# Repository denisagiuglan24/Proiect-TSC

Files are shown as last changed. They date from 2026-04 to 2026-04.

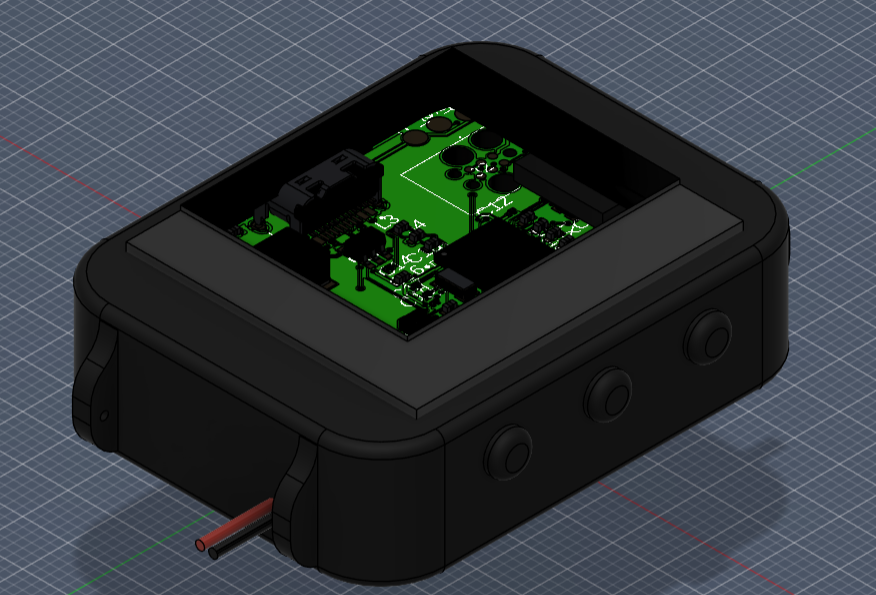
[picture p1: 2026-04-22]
Images/Screenshot 2026-04-22 121332.png

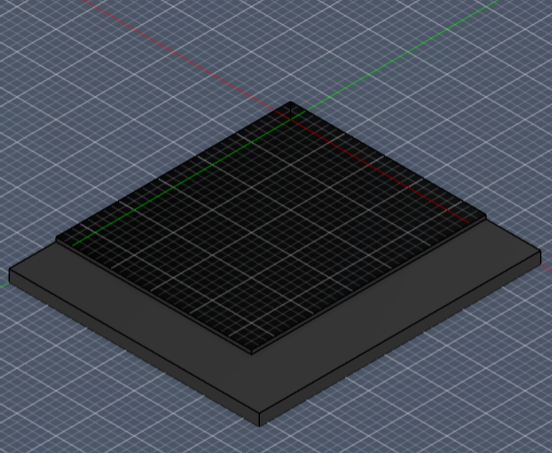
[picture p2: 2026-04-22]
Images/Screenshot 2026-04-22 121447.png

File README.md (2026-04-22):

# Proiect TSC - InkTime Smartwatch
**Student:** Giuglan Denisa-Cristina  
**Grupa:** 334CD  
---

## 1. Viziunea Proiectului si Arhitectura Sistemului

### Diagrama Bloc Hardware
Am structurat conexiunile pentru a separa magistrala rapida SPI (display) de magistrala senzorilor I2C, asigurand astfel o integritate maxima a semnalului.

```text
       ALIMENTARE (POWER)             SISTEM CENTRAL (MCU)                INTERFETE I/O
    _____________________          ___________________________          ____________________
   |                     |        |                           |        |                    |
   |   USB-C Connector   |---5V---|      nRF52840 (SoC)       |--SPI-->|   DISPLAY E-PAPER  |
   |_____________________|        |    Cortex-M4F @ 64MHz     |   Bus  |   (1.54" 24-pin)   |
              |                   |___________________________|        |____________________|
              v                    | P0.02 (SCK) | P0.03 (MOSI)
    _____________________          | P0.15 (DC)  | P0.16 (RST)          ____________________
   |                     |        |___________________________|        |                    |
   |   BQ25180 Charger   |--VBAT--|      MAGISTRALA I2C       |<------>|   ACCEL. BMA421    |
   |  (Li-Po Management) |        |      (SDA / SCL)          |   Bus  |   MAX17048 GAUGE   |
   |_____________________|        |___________________________|        |   DRV2605 HAPTIC   |
              ^                    | P0.26 (SDA) | P0.27 (SCL)         |____________________|
              |                    |___________________________|
    __________|__________          |                           |        ____________________
   |                     |         |   GPIO / PWM CONTROL      |       |                    |
   |   BATERIE LI-PO     |         |                           |------>|   MOTOR VIBRATII   |
   |      250 mAh        |         | P1.11 (PWM) | P0.13 (UP)  |       |____________________|
   |_____________________|         | P0.14 (ENT) | P1.02 (DN)  |<------|    3x BUTOANE      |
              |                    |___________________________|       |____________________|
              v                              |
    _____________________          __________|__________                ____________________
   |                     |        |                     |              |                    |
   |   RT6160A BUCK-B    |--3.3V--|   CRISTAL EXTERN    |------------->|      ANTENA RF     |
   |  (System Power)     |        |    (32.768 kHz)     |              |     (2.4 GHz)      |
   |_____________________|        |_____________________|              |____________________|
```
## 2. Documentatia Componentelor (BOM)

Am selectat componentele bazandu-ma pe catalogul **JLC Parts**, urmarind un raport optim intre dimensiune si performanta. Toate piesele pasive (rezistente/condensatoare) sunt in capsule **0201** si **0402**.

| Componenta | Package | Cod JLC Parts | Datasheet |
|:---|:---|:---|:---|
| **nRF52840-QIAA-R** (MCU) | aQFN73 | [C190794](https://jlcpcb.com/partdetail/Nordic_Semicon-NRF52840_QIAA_R/C190794) | [Link](https://docs.nordicsemi.com/) |
| **E-Paper Display 1.54"** | 24-pin FPC | [C359944](https://jlcpcb.com/partdetail/Waveshare-4_2inch_e_PaperModule/C359944) | [Link](https://www.waveshare.com/w/upload/e/e6/1.54inch_e-Paper_Datasheet.pdf) |
| **BQ25180YBGR** (Charger) | DSBGA-9 | [C3682423](https://jlcpcb.com/partdetail/TexasInstruments-BQ25180YBGR/C3682423) | [Link](https://www.ti.com/lit/ds/symlink/bq25180.pdf) |
| **RT6160AWSC** (Buck-Boost) | WLCSP-15 | [C7065276](https://jlcpcb.com/partdetail/Richtek_Tech-RT6160AWSC/C7065276) | [Link](https://www.richtek.com/assets/product_file/RT6160A/DS6160A-05.pdf) |
| **BMA421** (Accel) | LGA-12 | [C5242966](https://jlcpcb.com/partdetail/Bosch_Sensortec-BMA421/C5242966) | [Link](https://www.bosch-sensortec.com/media/boschsensortec/downloads/datasheets/bst-bma421-ds004.pdf) |
| **MAX17048G+T10** (Gauge) | DFN-8 | [C2682616](https://jlcpcb.com/partdetail/AnalogDevices-MAX17048G_T10/C2682616) | [Link](https://www.analog.com/media/en/technical-documentation/data-sheets/MAX17048-MAX17049.pdf) |
| **DRV2605YZFR** (Haptic) | VSSOP-10 | [C81079](https://jlcpcb.com/partdetail/TexasInstruments-DRV2605YZFR/C81079) | [Link](https://www.ti.com/lit/ds/symlink/drv2605.pdf) |
| **Antenna (2450AT18B100E)** | SMD 3216 | [C5179427](https://jlcpcb.com/partdetail/Johanson_Technology-2450AT18B100E/C5179427) | [Link](https://www.johansontechnology.com/datasheets/2450AT18B100/2450AT18B100.pdf) |
| **KH-TYPE-C-16P** (USB) | 16-pin SMD | [C2765186](https://jlcpcb.com/partdetail/Kinghelm-KH_TYPE_C_16P/C2765186) | [Link](https://datasheet.lcsc.com/lcsc/2012121836_Kinghelm-KH-TYPE-C-16P_C2765186.pdf) |
| **Molex 503480-2400** (FPC) | 24-pin SMD | [C2857168](https://jlcpcb.com/partdetail/Molex-5034802400/C2857160) | [Link](https://www.molex.com/en-us/products/part-detail/5034802400) |
| **USBLC6-2SC6Y** (ESD) | SOT-23-6 | [C7519](https://jlcpcb.com/partdetail/Stmicroelectronics-USBLC6_2SC6Y/C7519) | [Link](https://www.st.com/resource/en/datasheet/usblc6-2.pdf) |
| **Si2301CDS** (P-FET) | SOT-23 | [C10487](https://jlcpcb.com/partdetail/Vishay-Si2301CDS-T1-GE3/C10487) | [Link](https://www.vishay.com/docs/68749/si2301cds.pdf) |
| **EVP-AKB31A** (Butoane) | SMD Tactile | [C2845028](https://jlcpcb.com/partdetail/Panasonic-EVP_AKE31A/C2845028) | [Link](https://industrial.panasonic.com/cdbs/www-data/pdf/ATV0000/ATV0000CE3.pdf) |
| **Motor Vibratii** | Wire leads | [C7528006](https://jlcpcb.com/partdetail/7528806-LCM1027B3605F/C7528806) | [Link](https://datasheet.lcsc.com/lcsc/2310131633_LCM-LCM1027B3605F_C7528806.pdf) |
| **Crystal 32 MHz** | 2016 | [C5265841](https://jlcpcb.com/partdetail/Huiyuancrystal-HY32MSMD2016CA1R30/C5265841) | [Link](https://www.lcsc.com/product-detail/C7275071.html) |
| **Crystal 32.768 kHz** | 3215 | [C70509](https://jlcpcb.com/partdetail/NDK-NX3215SA_32_768KHZ_EXS00AMU00466/C70509) | [Link](https://www.ndk.com/images/products/catalog/c_NX3215SA_e.pdf) |
| **Inductor 0.47uH** | 2016 | [C5832368](https://jlcpcb.com/partdetail/6763488-FTC252012SR47MBCA/C5832368) | [Link](https://www.lcsc.com/product-detail/C5832368.html) |
| **Inductor 10uH** | 0402 | [C910650](https://jlcpcb.com/partdetail/MurataElectronics-LQW15DN100M00D/C910650) | [Link](https://www.murata.com/en-us/products/productdetail?partno=LQW15DN100M00%23) |
| **Rezistenta 10k Ω** | 0201 | [C100126](https://jlcpcb.com/partdetail/LIZElec-CR0201FH1002G/C100126) | [Link](https://www.lcsc.com/product-detail/C100126.html) |
| **Rezistenta 5.1k Ω** | 0201 | [C100142](https://jlcpcb.com/partdetail/LIZElec-CR0201FH5101G/C100142) | [Link](https://www.lcsc.com/product-detail/C5266011.html) |
| **Condensator 1uF** | 0402 | [C14445](https://jlcpcb.com/partdetail/15107-CL05A105KP5NNNC/C14445) | [Link](https://weblib.samsungsem.com/) |
| **Condensator 100nF** | 0201 | [C49062](https://jlcpcb.com/partdetail/50070-CL03A104KP3NNNC/C49062) | [Link](https://www.lcsc.com/product-detail/C49062.html) |
| **Condensator 4.7uF** | 0402 | [C23687](https://jlcpcb.com/partdetail/TDK-C1005X5R0J475MTJ00E/C23687) | [Link](https://www.lcsc.com/product-detail/C23687.html) |
| **Condensator 22uF** | 0402 | [C105226](https://jlcpcb.com/partdetail/106441-CL05A226MQ5QUNC/C105226) | [Link](https://www.lcsc.com/product-detail/C105226.html) |
| **Condensator 12pF** | 0201 | [C50391](https://jlcpcb.com/partdetail/51400-0201CG120J500NT/C50391) | [Link](https://www.lcsc.com/product-detail/C50391.html) |
| **LiPo 250mAh** | Baterie | - | [Link](https://www.tme.eu/Document/b9e12bf26ad0ba929a22ab5d58f022cd/AKY0106.pdf) |
| **TC2030-IDC** (Debug) | Footprint | - | [Link](https://www.tag-connect.com/product/tc2030-idc) |

---

## 3. Analiza Functionalitatii Hardware

In aceasta faza a proiectului, m-am concentrat pe implementarea unui sistem care sa poata functiona independent de o sursa de curent externa pentru perioade lungi.

### 3.1 Unitatea Centrala si Conectivitatea
Am optat pentru **nRF52840** datorita arhitecturii sale flexibile. Acesta imi permite sa folosesc USB-ul nativ pentru debug si transfer de date, in timp ce interfata radio BLE asigura sincronizarea cu telefonul. Pentru a asigura o precizie ridicata a timpului, am adaugat un cristal extern de **32.768 kHz**, esential pentru ca ceasul sa nu piarda secunde in modurile sleep.

### 3.2 Sistemul de Afisaj E-Paper
In loc de un ecran clasic care necesita iluminare constanta, am integrat un display E-Paper de 1.54 inch. Acesta utilizeaza particule incarcate electric care isi pastreaza pozitia fara consum de energie. Am conectat ecranul prin **SPI**, trimitand datele la frecventa maxima suportata pentru a finaliza refresh-ul rapid si a permite procesorului sa intre inapoi in starea de consum minim.

### 3.3 Managementul Energiei
Alimentarea este asigurata de o baterie Li-Po de 250mAh. Am integrat un circuit **Buck-Boost RT6160A** pentru a ma asigura ca, indiferent de nivelul de descarcare al bateriei (intre 4.2V si 3.0V), sistemul primeste un 3.3V stabil. Incarcarea este gestionata inteligent de **BQ25180**, iar monitorizarea procentului bateriei se face prin **MAX17048**, care raporteaza datele catre MCU prin magistrala I2C.

---

## 4. Alocarea Pinilor nRF52840 (Justificare Tehnica)

In procesul de layout, am ales pinii pentru a optimiza rutarea si a separa semnalele de mare viteza de cele de control.

| Pin nRF | Conectat la | Ratiune Tehnica / Explicatie |
|:---|:---|:---|
| **P0.02** | E-Paper SCK | Pin de clock SPI de mare viteza, ales pentru capabilitatea High-Drive. |
| **P0.03** | E-Paper MOSI | Linie de date SPI catre display, plasata langa clock pentru a asigura integritatea semnalului. |
| **P0.15** | E-Paper DC | Data/Command select, esential pentru protocolul controller-ului EPD. |
| **P0.26** | I2C SDA | Linie de date pentru magistrala comuna (IMU, Fuel Gauge, Haptic). |
| **P0.27** | I2C SCL | Semnal de ceas pentru magistrala I2C. |
| **P1.11** | PWM Haptic | Controlul motorului de vibratii, plasat pe Portul 1 pentru a izola zgomotul de comutatie. |
| **P0.13** | Button UP | Intrare GPIO cu rezistenta pull-up interna; poate trezi MCU din sleep (SENSE). |
| **P0.14** | Button ENTER| Intrare digitala pentru selectie si confirmare in meniu. |
| **P1.02** | Button DOWN | Navigare interfata utilizator. |
| **SWDIO / SWDCLK**| Debug/Prog | Interfata Serial Wire Debug folosita pentru programare prin header-ul Tag-Connect. |

---

## 5. Estimarea Consumului si Autonomia

Am proiectat InkTime cu un consum in "Deep Sleep" (System ON) estimat la **~84 uA** (MCU sleep, RTC activ, senzori in low-power).
* In timpul unui **refresh de ecran**, avem un varf de consum de pana la **15 mA** pentru o durata scurta.
* In modul **standby**, tehnologia E-Ink consuma **0 mA** pentru a mentine imaginea.

**Calcul Autonomie:** Cu o baterie de 250 mAh, la un regim de utilizare mediu (refresh ceas o data pe minut si notificari BLE), autonomia estimata este de **~30 de zile**, oferind o experienta superioara smartwatch-urilor clasice.

---

## 6. Design Mecanic si Integrare 3D

Integrarea componentelor a fost realizata in **Fusion 360**, adoptand o structura compacta de tip sandwich:
* **Carcasa Superioara:** Protejeaza display-ul si asigura etanseitatea.
* **PCB:** Placa de 2 straturi pe care sunt montate toate componentele SMD.
* **Carcasa Inferioara:** Gazduieste bateria Li-Po si motorul haptic, fiind fixata prin presare si suruburi de precizie.
Am generat fisierele **.step** pentru vederea explodata si **.f3z** pentru proiectul sursa, asigurand compatibilitatea cu procesele de fabricatie.

---

## 📂 Organizare Repository
* **/Hardware**: Schema electronica (.sch) si design PCB (.brd).
* **/Manufacturing**: Arhiva Gerber, fisiere BOM si Pick&Place.
* **/Mechanical**: Modele CAD 3D (.step, .f3z).
* **/Images**: Randari si capturi de ecran.

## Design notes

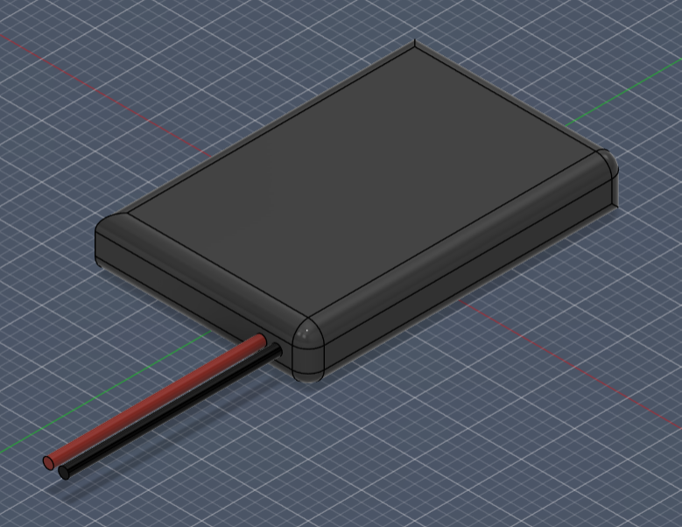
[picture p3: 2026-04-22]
Images/Screenshot 2026-04-22 121418.png

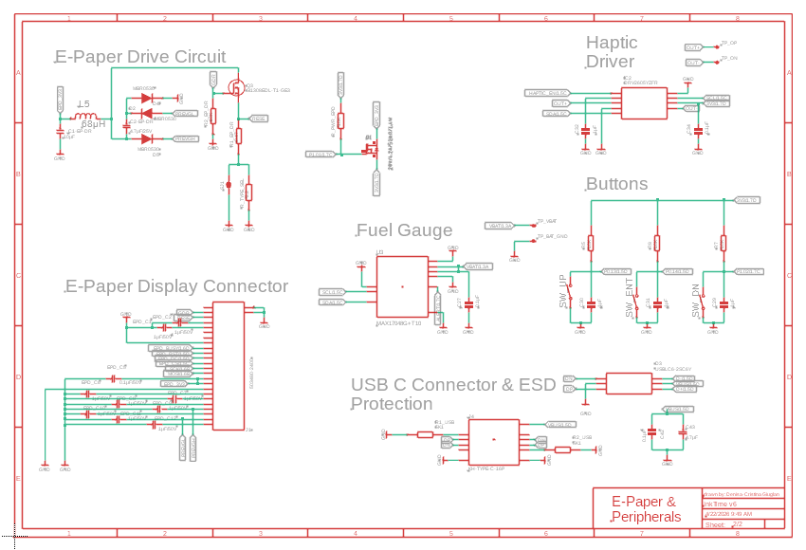
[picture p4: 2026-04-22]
Images/Screenshot 2026-04-22 121138.png

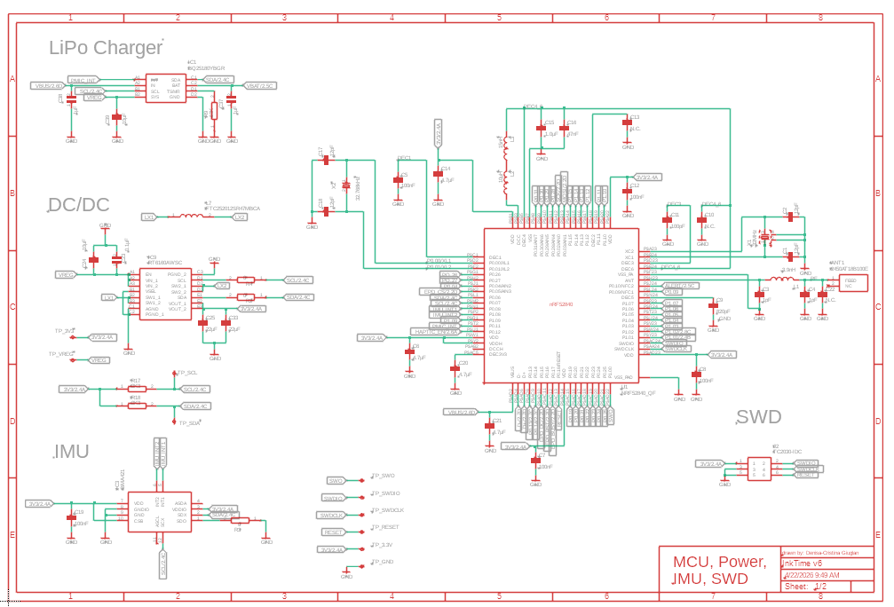
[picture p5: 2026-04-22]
Images/Screenshot 2026-04-22 121126.png

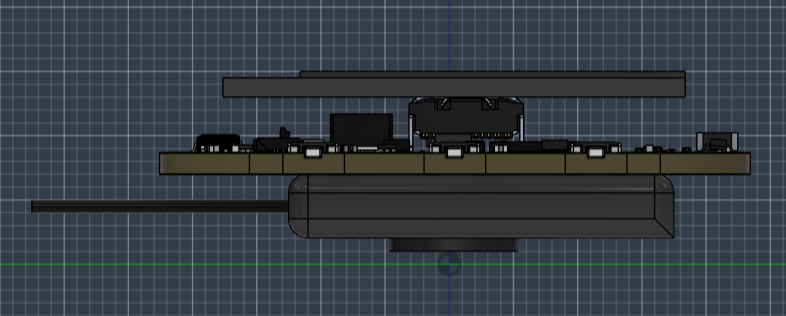
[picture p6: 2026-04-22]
Images/Screenshot 2026-04-22 121350.png

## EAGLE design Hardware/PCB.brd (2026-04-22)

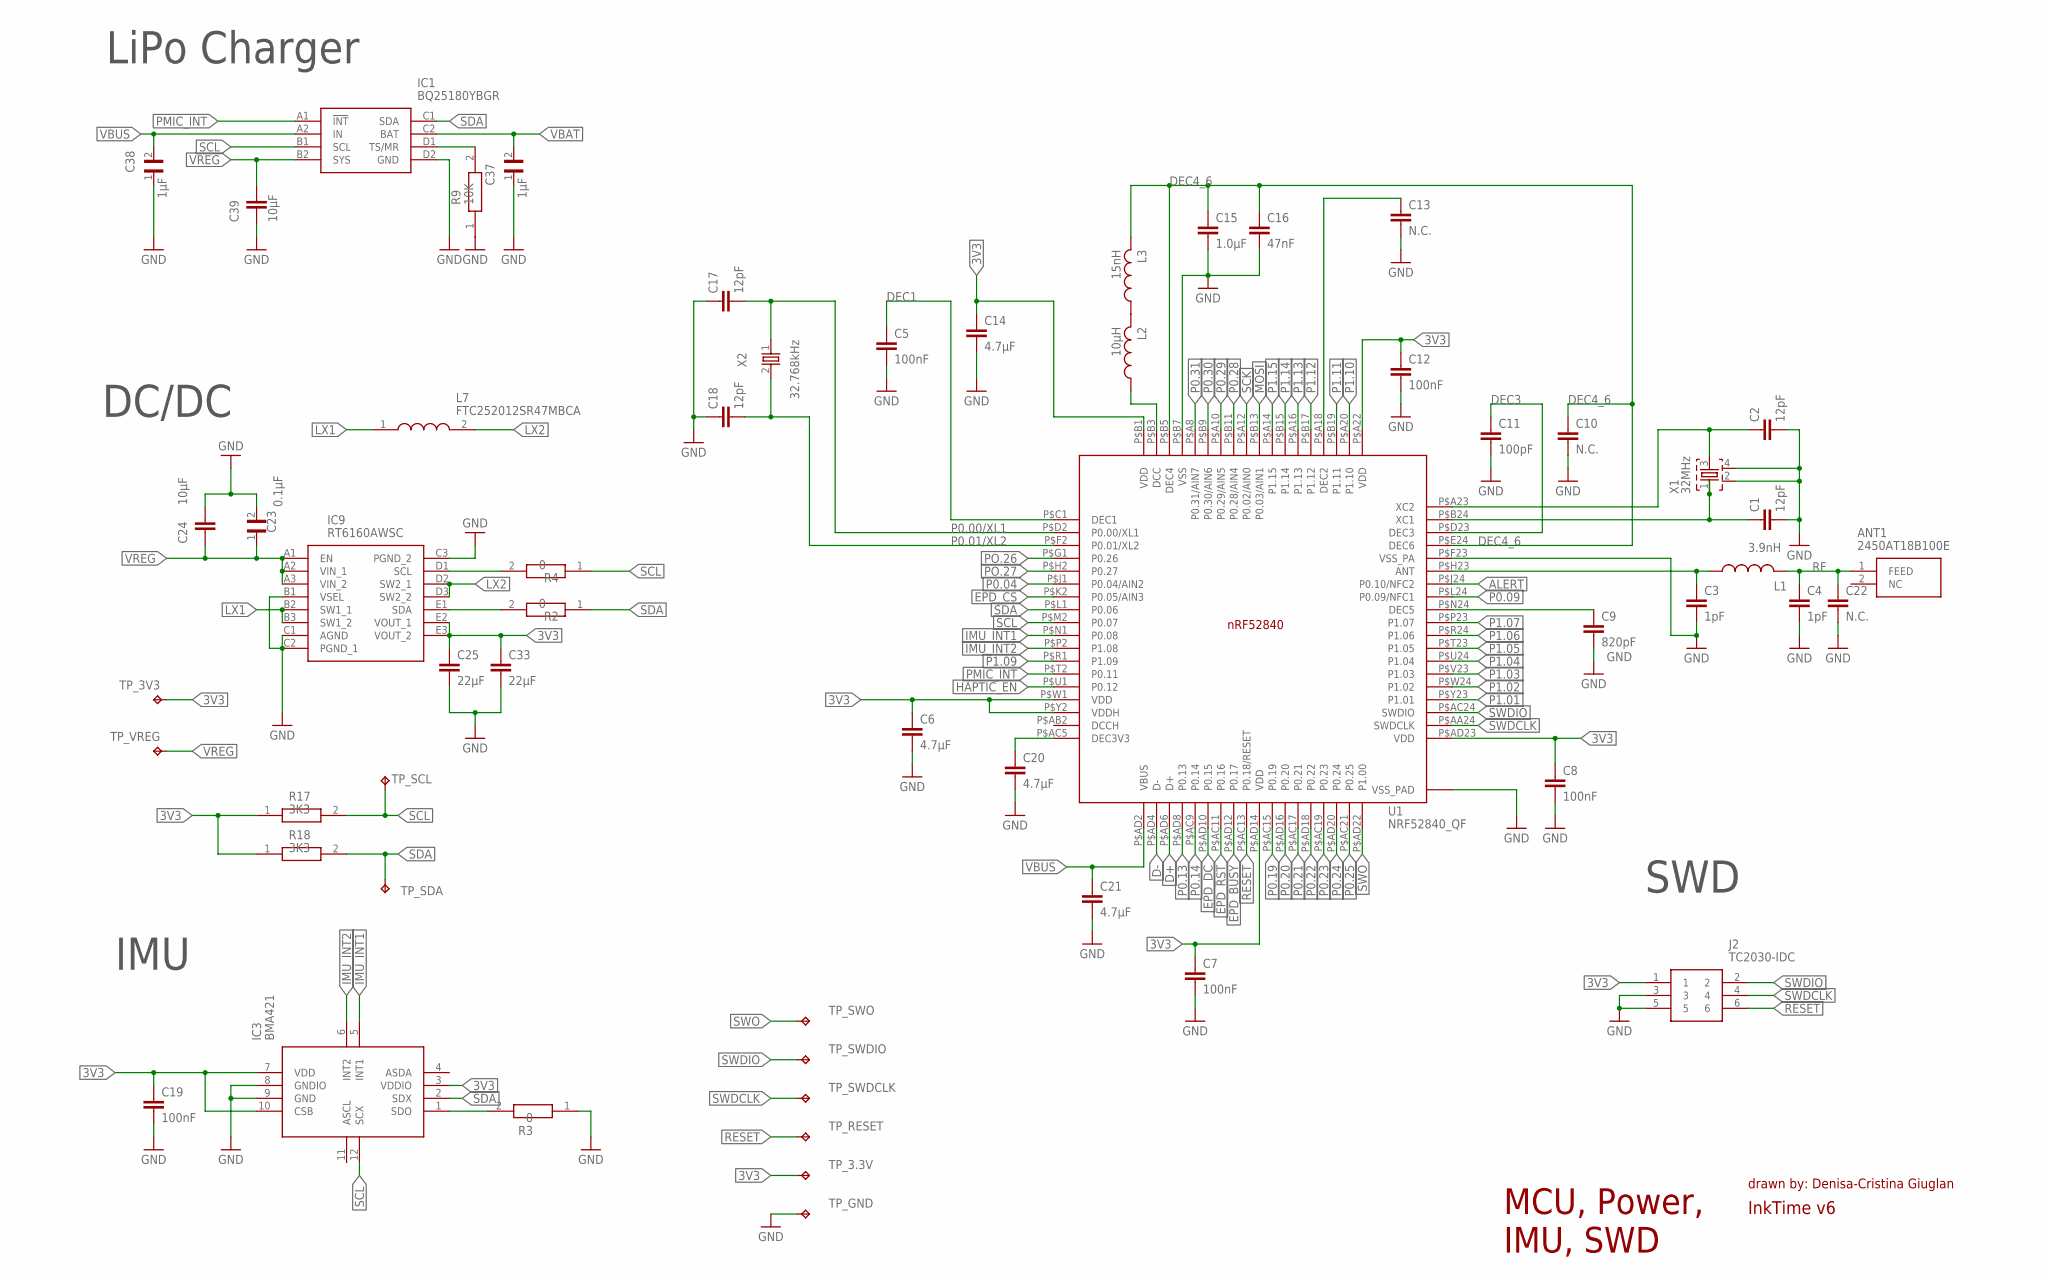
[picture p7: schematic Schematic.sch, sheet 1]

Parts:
ANT1: 2450AT18B100E; 2450AT18B100E_ANTC3216X140N
C1, C2, C17, C18: 12pF; NORDIC_NRF_3_RESC0201_L
C3: 1pF; NORDIC_NRF_3_RESC0402_N
C4: 1pF; NORDIC_NRF_3_RESC0201_L
C5, C7, C8, C12, C19: 100nF; NORDIC_NRF_3_RESC0201_L
C6, C14, C20, C21: 4.7μF; NORDIC_NRF_3_RESC0402_N
C9: 820pF; NORDIC_NRF_3_RESC0201_L
C10, C13, C22: N.C.; NORDIC_NRF_3_RESC0402_N
C11: 100pF; NORDIC_NRF_3_RESC0402_N
C15: 1.0μF; NORDIC_NRF_3_RESC0402_N
C16: 47nF; NORDIC_NRF_3_RESC0201_L
C23: 0.1μF; GRM011R60J152KE01L_2_CAPC0201X13N
C24, C39: 10μF; NORDIC_NRF_3_RESC0402_N
C25, C33: 22μF; NORDIC_NRF_3_RESC0402_N
C37, C38: 1μF; GRM011R60J152KE01L_2_CAPC0201X13N
IC1: BQ25180YBGR; BQ25180YBGR_BGA8C40P2X4_100X155X50
IC3: BMA421; BMA423_BMA423
IC9: RT6160AWSC; RT6160AWSC_BGA15C40P3X5_140X230X60
J2: TC2030-IDC; TC2030-IDC_TC2030IDC
L1: 3.9nH; NORDIC_NRF_2_RESC0402_L
L2: 10μH; NORDIC_NRF_2_RESC0402_L
L3: 15nH; NORDIC_NRF_2_RESC0402_L
L7: FTC252012SR47MBCA; MLP2016SR47MT0S1_INDC2016X100N
R2, R3, R4: 0; CPF0201D7K68C1_0201
R9: 10K; CPF0201D7K68C1_0201
R17, R18: 3K3; CPF0201D7K68C1_0201
TP_3.3V, TP_3V3: HECTOR_WATCH_1_TPTP20R; HECTOR_WATCH_1_TP20R
TP_GND: HECTOR_WATCH_1_TPTP20R; HECTOR_WATCH_1_TP20R
TP_RESET: HECTOR_WATCH_1_TPTP20R; HECTOR_WATCH_1_TP20R
TP_SCL: HECTOR_WATCH_1_TPTP20R; HECTOR_WATCH_1_TP20R
TP_SDA: HECTOR_WATCH_1_TPTP20R; HECTOR_WATCH_1_TP20R
TP_SWDCLK: HECTOR_WATCH_1_TPTP20R; HECTOR_WATCH_1_TP20R
TP_SWDIO: HECTOR_WATCH_1_TPTP20R; HECTOR_WATCH_1_TP20R
TP_SWO: HECTOR_WATCH_1_TPTP20R; HECTOR_WATCH_1_TP20R
TP_VREG: HECTOR_WATCH_1_TPTP20R; HECTOR_WATCH_1_TP20R
U1: NRF52840_QF; NORDIC_NRF_4_AQFN50P700X700X85_HS-74N
X1: 32MHz; NORDIC_NRF_BT-XTAL_2016_N
X2: 32.768kHz; NORDIC_NRF_1_XTAL_3215_N

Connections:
3V3: C6.1, C7.1, C8.1, C12.1, C14.1, C19.1, C25.1, C33.1, IC3.3 (VDDIO), IC3.7 (VDD), IC3.10 (CSB), IC9.E2 (VOUT_1), IC9.E3 (VOUT_2), J2.1, R17.1, R18.1, TP_3.3V.TP, TP_3V3.TP, U1.P$A22 (VDD), U1.P$AD14 (VDD), U1.P$AD23 (VDD), U1.P$B1 (VDD), U1.P$W1 (VDD), U1.P$Y2 (VDDH); also elsewhere on the board
ALERT: U1.P$J24 (P0.10/NFC2); also elsewhere on the board
D+: U1.P$AD6 (D+); also elsewhere on the board
D-: U1.P$AD4 (D-); also elsewhere on the board
DEC1: C5.1, U1.P$C1 (DEC1)
DEC3: C11.1, U1.P$D23 (DEC3)
DEC4_6: C10.1, C15.1, C16.1, L3.2, U1.P$B5 (DEC4), U1.P$E24 (DEC6)
EPD_BUSY: U1.P$AD12 (P0.17); also elsewhere on the board
EPD_CS: U1.P$K2 (P0.05/AIN3); also elsewhere on the board
EPD_DC: U1.P$AD10 (P0.15); also elsewhere on the board
EPD_RST: U1.P$AC11 (P0.16); also elsewhere on the board
GND: C1.2, C2.2, C3.2, C4.2, C5.2, C6.2, C7.2, C8.2, C9.2, C10.2, C11.2, C12.2, C13.2, C14.2, C15.2, C16.2, C17.1, C18.1, C19.2, C20.2, C21.2, C22.2, C23.2, C24.1, C25.2, C33.2, C37.1, C38.1, C39.2, IC1.D2 (GND), IC3.8 (GNDIO), IC3.9 (GND), IC9.B1 (VSEL), IC9.C1 (AGND), IC9.C2 (PGND_1), IC9.C3 (PGND_2), J2.3, J2.5, R3.1, R9.1, TP_GND.TP, U1.P$74 (VSS_PAD), U1.P$75 (VSS_PAD), U1.P$76 (VSS_PAD), U1.P$77 (VSS_PAD), U1.P$78 (VSS_PAD), U1.P$79 (VSS_PAD), U1.P$80 (VSS_PAD), U1.P$81 (VSS_PAD), U1.P$82 (VSS_PAD), U1.P$83 (VSS_PAD), U1.P$84 (VSS_PAD), U1.P$85 (VSS_PAD), U1.P$86 (VSS_PAD), U1.P$87 (VSS_PAD), U1.P$88 (VSS_PAD), U1.P$89 (VSS_PAD), U1.P$90 (VSS_PAD), U1.P$B7 (VSS), U1.P$F23 (VSS_PA), X1.2, X1.4; also elsewhere on the board
HAPTIC_EN: U1.P$U1 (P0.12); also elsewhere on the board
IMU_INT1: IC3.5 (INT1), U1.P$N1 (P0.08)
IMU_INT2: IC3.6 (INT2), U1.P$P2 (P1.08)
LX1: IC9.B2 (SW1_1), IC9.B3 (SW1_2), L7.1
LX2: IC9.D2 (SW2_1), IC9.D3 (SW2_2), L7.2
MOSI: U1.P$B13 (P0.03/AIN1); also elsewhere on the board
unnamed: IC9.D1 (SCL), R4.2
unnamed: C20.1, U1.P$AC5 (DEC3V3)
unnamed: IC9.E1 (SDA), R2.2
unnamed: L2.1, U1.P$B3 (DCC)
unnamed: IC1.D1 (TS/MR), R9.2
unnamed: IC3.1 (SDO), R3.2
unnamed: L2.2, L3.1
unnamed: C13.1, U1.P$A18 (DEC2)
unnamed: C9.1, U1.P$N24 (DEC5)
unnamed: C3.1, L1.1, U1.P$H23 (ANT)
unnamed: C2.1, U1.P$A23 (XC2), X1.3
unnamed: C1.1, U1.P$B24 (XC1), X1.1
P0.00/XL1: C17.2, U1.P$D2 (P0.00/XL1), X2.1
P0.01/XL2: C18.2, U1.P$F2 (P0.01/XL2), X2.2
P0.04: U1.P$J1 (P0.04/AIN2)
P0.09: U1.P$L24 (P0.09/NFC1)
P0.13: U1.P$AD8 (P0.13); also elsewhere on the board
P0.14: U1.P$AC9 (P0.14); also elsewhere on the board
P0.19: U1.P$AC15 (P0.19)
P0.20: U1.P$AD16 (P0.20)
P0.21: U1.P$AC17 (P0.21)
P0.22: U1.P$AD18 (P0.22)
P0.23: U1.P$AC19 (P0.23)
P0.24: U1.P$AD20 (P0.24)
P0.25: U1.P$AC21 (P0.25)
P0.28: U1.P$B11 (P0.28/AIN4)
P0.29: U1.P$A10 (P0.29/AIN5)
P0.30: U1.P$B9 (P0.30/AIN6)
P0.31: U1.P$A8 (P0.31/AIN7)
P1.01: U1.P$Y23 (P1.01); also elsewhere on the board
P1.02: U1.P$W24 (P1.02); also elsewhere on the board
P1.03: U1.P$V23 (P1.03)
P1.04: U1.P$U24 (P1.04)
P1.05: U1.P$T23 (P1.05)
P1.06: U1.P$R24 (P1.06)
P1.07: U1.P$P23 (P1.07)
P1.09: U1.P$R1 (P1.09)
P1.10: U1.P$A20 (P1.10)
P1.11: U1.P$B19 (P1.11)
P1.12: U1.P$B17 (P1.12)
P1.13: U1.P$A16 (P1.13)
P1.14: U1.P$B15 (P1.14)
P1.15: U1.P$A14 (P1.15)
PMIC_INT: IC1.A1 (!INT), U1.P$T2 (P0.11)
PO.26: U1.P$G1 (P0.26)
PO.27: U1.P$H2 (P0.27)
RESET: J2.6, TP_RESET.TP, U1.P$AC13 (P0.18/RESET)
RF: ANT1.1 (FEED), C4.1, C22.1, L1.2
SCK: U1.P$A12 (P0.02/AIN0); also elsewhere on the board
SCL: IC1.B1 (SCL), IC3.12 (SCX), R4.1, R17.2, TP_SCL.TP, U1.P$M2 (P0.07); also elsewhere on the board
SDA: IC1.C1 (SDA), IC3.2 (SDX), R2.1, R18.2, TP_SDA.TP, U1.P$L1 (P0.06); also elsewhere on the board
SWDCLK: J2.4, TP_SWDCLK.TP, U1.P$AA24 (SWDCLK)
SWDIO: J2.2, TP_SWDIO.TP, U1.P$AC24 (SWDIO)
SWO: TP_SWO.TP, U1.P$AD22 (P1.00)
VBAT: C37.2, IC1.C2 (BAT); also elsewhere on the board
VBUS: C21.1, C38.2, IC1.A2 (IN), U1.P$AD2 (VBUS); also elsewhere on the board
VREG: C23.1, C24.2, C39.1, IC1.B2 (SYS), IC9.A1 (EN), IC9.A2 (VIN_1), IC9.A3 (VIN_2), TP_VREG.TP

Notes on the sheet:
LiPo Charger
DC/DC
IMU
SWD
MCU, Power, IMU, SWD
InkTime v6
drawn by: Denisa-Cristina Giuglan

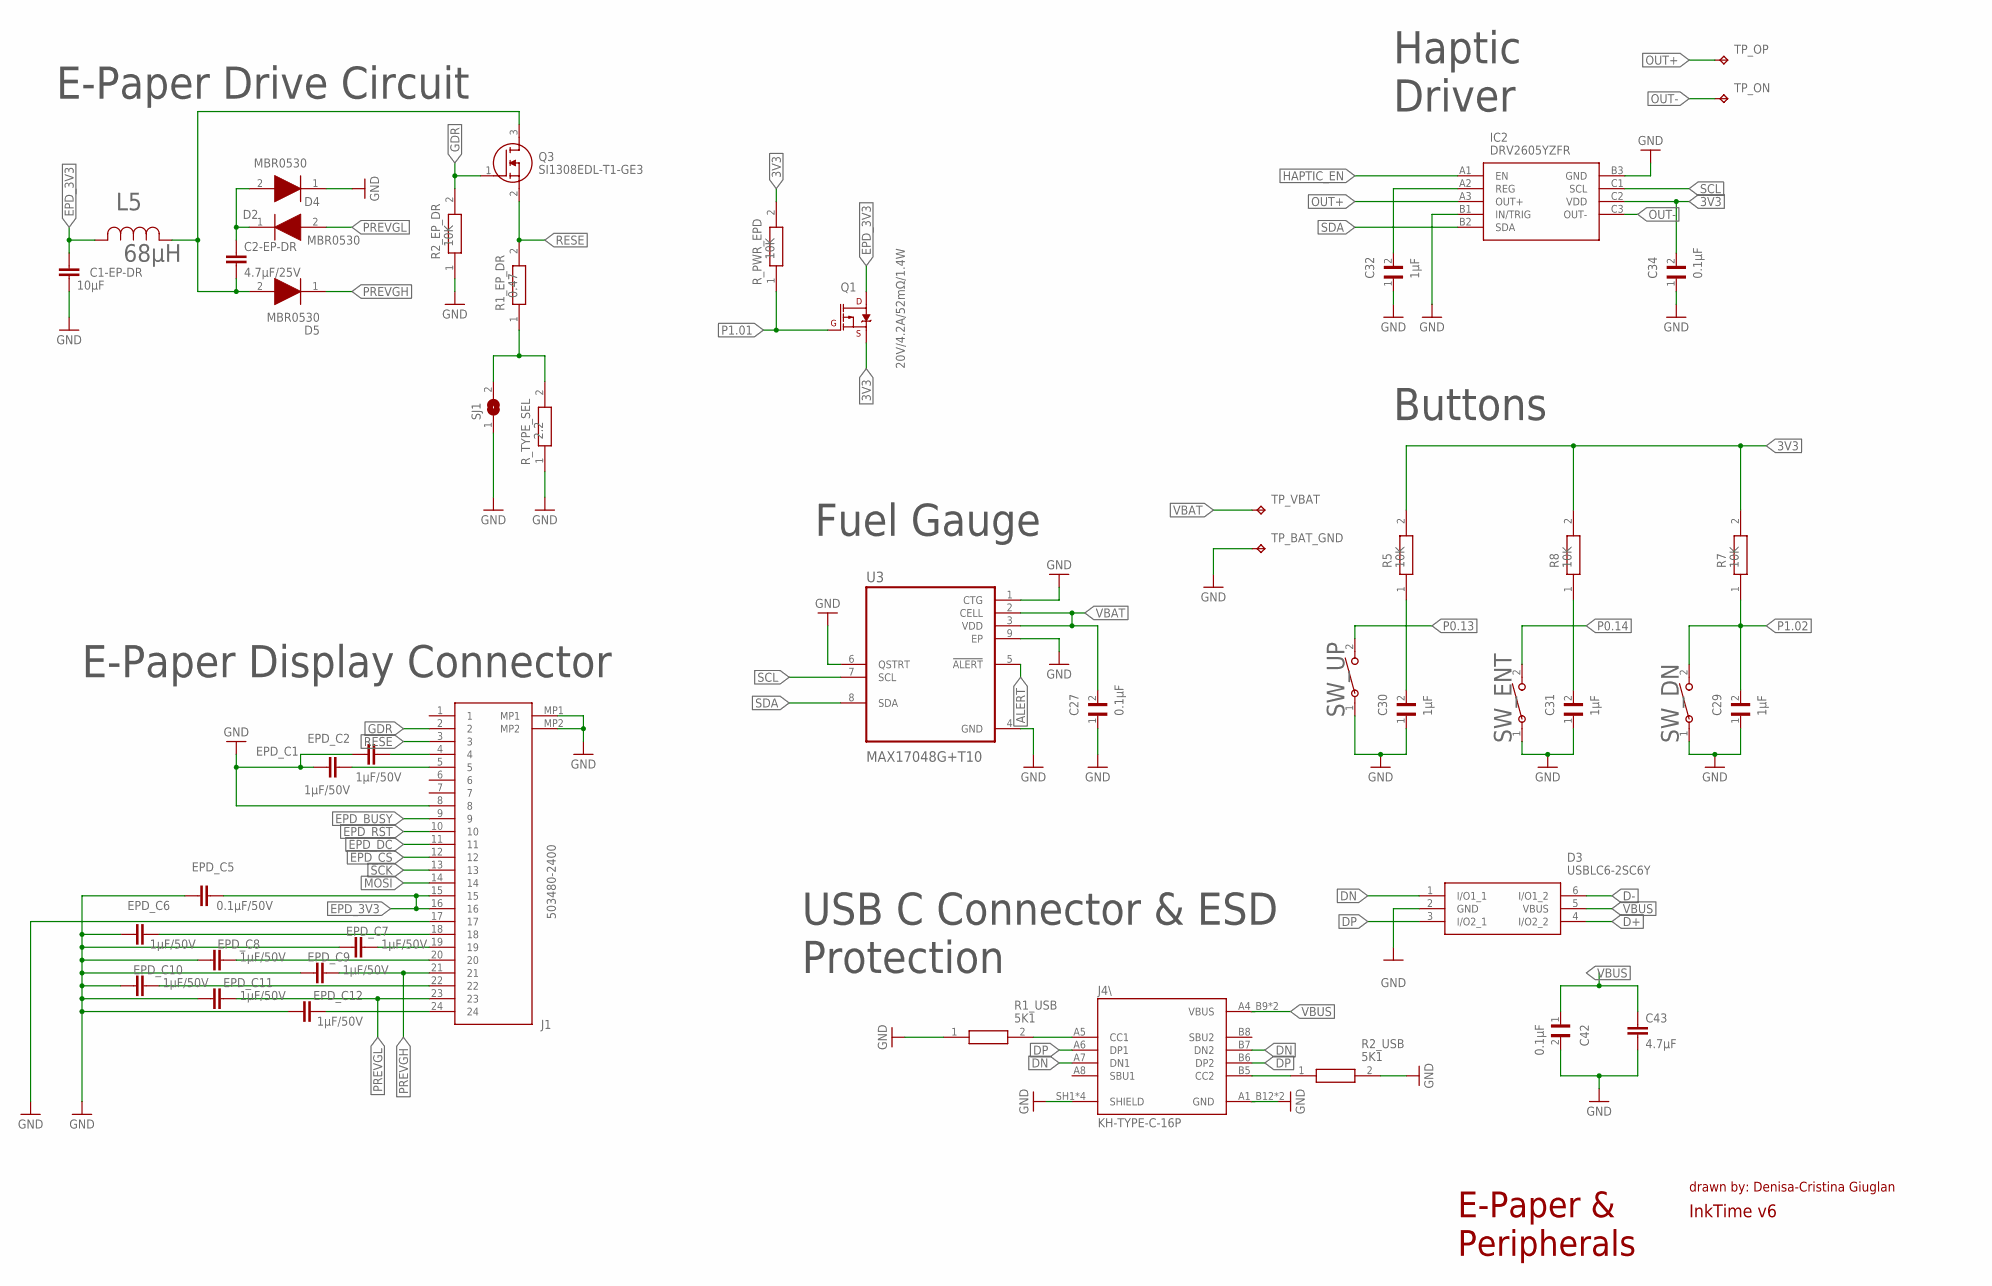
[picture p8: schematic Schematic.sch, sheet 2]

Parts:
C1-EP-DR: 10μF; NORDIC_NRF_3_RESC0402_N
C2-EP-DR: 4.7μF/25V; NORDIC_NRF_3_RESC0402_N
C27, C34, C42: 0.1μF; GRM011R60J152KE01L_2_CAPC0201X13N
C29, C30, C31, C32: 1μF; GRM011R60J152KE01L_2_CAPC0201X13N
C43: 4.7μF; NORDIC_NRF_3_RESC0402_N
D2, D4, D5: MBR0530; ESP32_C6_LIBRARY_5_SOD3716X135N
D3: USBLC6-2SC6Y; ESP32_C6_LIBRARY_3_SOT95P280X145-6N
EPD_C1, EPD_C2, EPD_C6, EPD_C7, EPD_C8, EPD_C9, EPD_C10, EPD_C11, EPD_C12: 1μF/50V; NORDIC_NRF_3_RESC0402_N
EPD_C5: 0.1μF/50V; NORDIC_NRF_3_RESC0402_N
IC2: DRV2605YZFR; DRV2605YZFR_BGA9C50P3X3_144X144X62
J1: 503480-2400; 503480-2400_5034802400
J4\: KH-TYPE-C-16P; KH-TYPE-C-16P_KINGHELM_KH-TYPE-C-16P
L5: 68μH; ESP32_C6_LIBRARY_2_IND_4828-WE-TPC_WRE
Q1: 20V/4.2A/52mΩ/1.4W; ESP32_C6_LIBRARY_4_ESP32_C6_LIBRARY_4_ESP32_C6_LIBRARY_4_ES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
Q3: SI1308EDL-T1-GE3; ESP32_C6_LIBRARY_6_SOT65P210X110-3N
R1_EP_DR: 0.47; CPF0201D7K68C1_0201
R1_USB, R2_USB: 5K1; CPF0201D7K68C1_0201
R2_EP_DR, R5, R7, R8: 10K; CPF0201D7K68C1_0201
R_PWR_EPD: 10K; CPF0201D7K68C1_0201
R_TYPE_SEL: 2.2; CPF0201D7K68C1_0201
SJ1: ESP32_C6_LIBRARY_7_JUMPER_SJ
SW_DN: 2025-10-22_07-23-44_LIBRARY_EVP-AKE31ASW_EVP-AKE3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; 2025-10-22_07-23-44_LIBRARY_SW_EVP-AKE31A_PAN
SW_ENT: 2025-10-22_07-23-44_LIBRARY_EVP-AKE31ASW_EVP-AKE3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; 2025-10-22_07-23-44_LIBRARY_SW_EVP-AKE31A_PAN
SW_UP: 2025-10-22_07-23-44_LIBRARY_EVP-AKE31ASW_EVP-AKE3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; 2025-10-22_07-23-44_LIBRARY_SW_EVP-AKE31A_PAN
TP_BAT_GND: HECTOR_WATCH_1_TPTP20R; HECTOR_WATCH_1_TP20R
TP_ON: HECTOR_WATCH_1_TPTP20R; HECTOR_WATCH_1_TP20R
TP_OP: HECTOR_WATCH_1_TPTP20R; HECTOR_WATCH_1_TP20R
TP_VBAT: HECTOR_WATCH_1_TPTP20R; HECTOR_WATCH_1_TP20R
U3: MAX17048G+T10; ESP32_C6_LIBRARY_SON50P200X200X80-9N

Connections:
3V3: C34.2, IC2.C2 (VDD), Q1.2 (S), R5.2, R7.2, R8.2, R_PWR_EPD.2; also elsewhere on the board
ALERT: U3.5 (!ALERT); also elsewhere on the board
D+: D3.4 (I/O2_2); also elsewhere on the board
D-: D3.6 (I/O1_2); also elsewhere on the board
DN: D3.1 (I/O1_1), J4\.A7 (DN1), J4\.B7 (DN2)
DP: D3.3 (I/O2_1), J4\.A6 (DP1), J4\.B6 (DP2)
EPD_3V3: C1-EP-DR.1, EPD_C5.2, J1.15, J1.16, L5.2, Q1.3 (D)
EPD_BUSY: J1.9; also elsewhere on the board
EPD_CS: J1.12; also elsewhere on the board
EPD_DC: J1.11; also elsewhere on the board
EPD_RST: J1.10; also elsewhere on the board
GDR: J1.2, Q3.1 (G), R2_EP_DR.2
GND: C1-EP-DR.2, C27.1, C29.1, C30.1, C31.1, C32.1, C34.1, C42.2, C43.2, D3.2 (GND), D4.1 (K), EPD_C1.1, EPD_C2.1, EPD_C5.1, EPD_C6.1, EPD_C7.1, EPD_C8.1, EPD_C9.1, EPD_C10.1, EPD_C11.1, EPD_C12.1, IC2.B1 (IN/TRIG), IC2.B3 (GND), J1.8, J1.17, J1.MP1, J1.MP2, J4\.A1_B12 (GND), J4\.A12_B1 (GND), J4\.SH1 (SHIELD), J4\.SH2 (SHIELD), J4\.SH3 (SHIELD), J4\.SH4 (SHIELD), R1_USB.1, R2_EP_DR.1, R2_USB.2, R_TYPE_SEL.1, SJ1.1, SW_DN.1, SW_ENT.1, SW_UP.1, TP_BAT_GND.TP, U3.1 (CTG), U3.4 (GND), U3.6 (QSTRT), U3.9 (EP); also elsewhere on the board
HAPTIC_EN: IC2.A1 (EN); also elsewhere on the board
MOSI: J1.14; also elsewhere on the board
unnamed: J4\.A5 (CC1), R1_USB.2
unnamed: EPD_C2.2, J1.4
unnamed: EPD_C1.2, J1.5
unnamed: J4\.B5 (CC2), R2_USB.1
unnamed: C31.2, R8.1
unnamed: C2-EP-DR.1, D2.1 (K), D4.2 (A)
unnamed: C30.2, R5.1
unnamed: C2-EP-DR.2, D5.2 (A), L5.1, Q3.3 (D)
unnamed: EPD_C6.2, J1.18
unnamed: C32.2, IC2.A2 (REG)
unnamed: EPD_C7.2, J1.19
unnamed: EPD_C8.2, J1.20
unnamed: EPD_C10.2, J1.22
unnamed: EPD_C12.2, J1.24
unnamed: R1_EP_DR.1, R_TYPE_SEL.2, SJ1.2
OUT+: IC2.A3 (OUT+), TP_OP.TP
OUT-: IC2.C3 (OUT-), TP_ON.TP
P0.13: SW_UP.2; also elsewhere on the board
P0.14: SW_ENT.2; also elsewhere on the board
P1.01: Q1.1 (G), R_PWR_EPD.1; also elsewhere on the board
P1.02: C29.2, R7.1, SW_DN.2; also elsewhere on the board
PREVGH: D5.1 (K), EPD_C9.2, J1.21
PREVGL: D2.2 (A), EPD_C11.2, J1.23
RESE: J1.3, Q3.2 (S), R1_EP_DR.2
SCK: J1.13; also elsewhere on the board
SCL: IC2.C1 (SCL), U3.7 (SCL); also elsewhere on the board
SDA: IC2.B2 (SDA), U3.8 (SDA); also elsewhere on the board
VBAT: C27.2, TP_VBAT.TP, U3.2 (CELL), U3.3 (VDD); also elsewhere on the board
VBUS: C42.1, C43.1, D3.5 (VBUS), J4\.A4_B9 (VBUS), J4\.A9_B4 (VBUS); also elsewhere on the board

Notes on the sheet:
E-Paper Drive Circuit
E-Paper Display Connector
Haptic Driver
Buttons
Fuel Gauge
USB C Connector & ESD Protection
E-Paper & Peripherals
InkTime v6
drawn by: Denisa-Cristina Giuglan

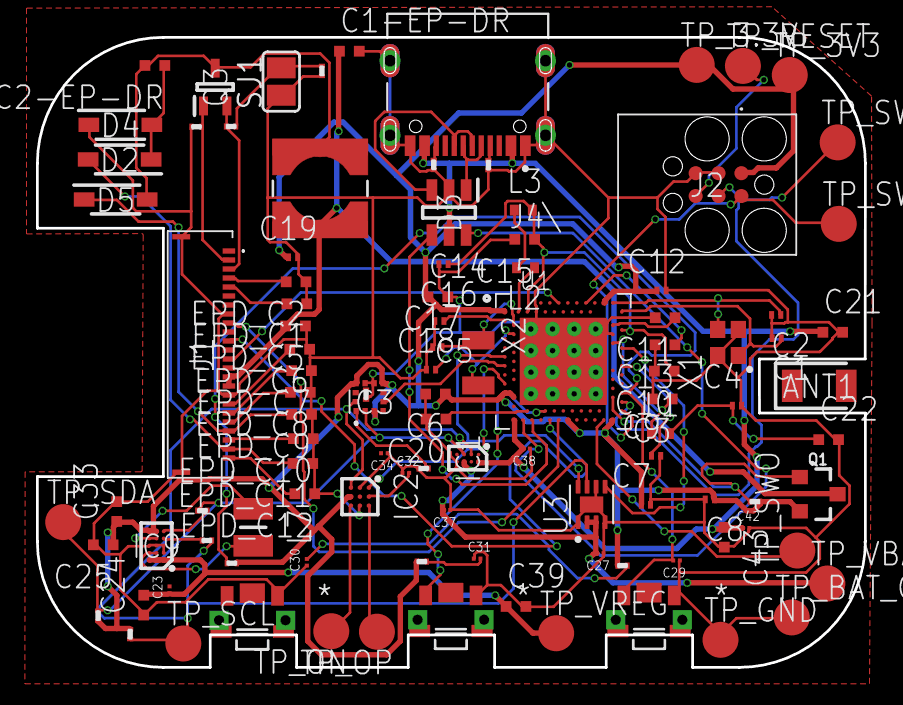
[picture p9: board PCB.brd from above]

Board: 2 copper layers, 46.0 x 35.0 mm, 105 parts (0 on the bottom side), 72 nets.

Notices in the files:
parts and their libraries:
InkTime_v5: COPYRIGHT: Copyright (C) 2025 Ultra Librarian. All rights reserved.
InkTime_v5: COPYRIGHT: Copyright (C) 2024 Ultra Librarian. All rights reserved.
